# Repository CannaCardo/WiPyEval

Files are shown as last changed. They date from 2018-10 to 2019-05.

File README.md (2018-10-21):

# WiPy Eval
> WiPy 3.0 Evaluation board 




The board incorporates USB-UART bridge, micro SD card holder and temperature/ humidity sensor. The board was designed to be used by students, and as such has current limiting resistors in series with buttons in case of accidental press while GPIO is used by other peripherals. It also uses stackable headers for ease of connection and usage with both breadbords and shields/ modules.



## Release History

* 0.1.0
    * First Prototype

## Meta

Krzysztof Belewicz – belewicz@gmail.com

Distributed under the Beerware license. If you decide to build your own feel free to send me a pic.

[https://github.com/CannaCardo/github-link](https://github.com/CannaCardo/)

<!-- Markdown link & img dfn's -->
[Ver-image]: https://img.shields.io/badge/Version-1.0-orange.svg?longCache=true&style=flat-square
[Stat-image]: https://img.shields.io/badge/Status-Manufacture-green.svg?longCache=true&style=flat-square
[wiki]: https://github.com/CannaCardo/WiPy_Eval/wiki

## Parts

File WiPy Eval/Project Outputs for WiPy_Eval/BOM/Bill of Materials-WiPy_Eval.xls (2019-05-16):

Designator | Description | Value | Tolerance | MaxVoltage | Quantity | Manufacturer 1 | Manufacturer Part Number 1 | Supplier 1 | Supplier Part Number 1 | Manufacturer 2 | Manufacturer Part Number 2 | Supplier 2 | Supplier Part Number 2
A1, A2 | Bluetooth / WLAN / WiFi Ceramic Chip Antenna W x L x H (3.2 x 1.6 x 1.1 mm) |  |  |  | 2 | Pulse Electronics (https://octopart-clicks.com/click/altium?sku=2897223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) | W3008 (https://octopart-clicks.com/click/altium?sku=2897223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) | Farnell | 2897223 (https://octopart-clicks.com/click/altium?sku=2897223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) | Pulse Electronics (https://octopart-clicks.com/click/altium?sku=673-W3008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) | W3008 (https://octopart-clicks.com/click/altium?sku=673-W3008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) | Mouser | 673-W3008 (https://octopart-clicks.com/click/altium?sku=673-W3008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)
A3 | 1.575 GHz (GPS L1) 3 dBi SMD 50Ohm chip antenna, 3216 (metric) 3.2x1.6x0.6 mm |  |  |  | 1 | Walsin Technologies (https://octopart-clicks.com/click/altium?sku=RFECA3216060E0T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) | RFECA3216060E0T (https://octopart-clicks.com/click/altium?sku=RFECA3216060E0T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) | TME | RFECA3216060E0T (https://octopart-clicks.com/click/altium?sku=RFECA3216060E0T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)
C1, C2, C7, C13, C15, C20, C24 | 0402 SMD Capacitor | 2.2u | 10% | 6.3V | 7 | Murata (https://octopart-clicks.com/click/altium?sku=2672104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) | GRT155C80J225KE01D (https://octopart-clicks.com/click/altium?sku=2672104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) | Farnell | 2672104 (https://octopart-clicks.com/click/altium?sku=2672104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) | Samsung (https://octopart-clicks.com/click/altium?sku=CL05A225KQ5NSNC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) | CL05A225KQ5NSNC (https://octopart-clicks.com/click/altium?sku=CL05A225KQ5NSNC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) | TME | CL05A225KQ5NSNC (https://octopart-clicks.com/click/altium?sku=CL05A225KQ5NSNC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)
C3, C8, C11, C12, C14, C16, C17, C19, C21, C23, C37, C40, C47 | 0402 SMD Capacitor | 100n | 10% | 16V | 13 | Multicomp (https://octopart-clicks.com/click/altium?sku=2627343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) | MC0402B104K100CT (https://octopart-clicks.com/click/altium?sku=2627343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) | Farnell | 2627343 (https://octopart-clicks.com/click/altium?sku=2627343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) | Samsung (https://octopart-clicks.com/click/altium?sku=CL05B104KO5NNNC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) | CL05B104KO5NNNC (https://octopart-clicks.com/click/altium?sku=CL05B104KO5NNNC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) | TME | CL05B104KO5NNNC (https://octopart-clicks.com/click/altium?sku=CL05B104KO5NNNC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)
C4, C6, C25, C26, C27, C28, C29, C30, C46 | 0402 SMD Capacitor | DNP |  |  | 9
C5 | 0402 SMD Capacitor | 100p | 10% | 25V | 1 | Kyocera AVX (https://octopart-clicks.com/click/altium?sku=04025A101JAT2A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) | 04025A101JAT2A (https://octopart-clicks.com/click/altium?sku=04025A101JAT2A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) | TME | 04025A101JAT2A (https://octopart-clicks.com/click/altium?sku=04025A101JAT2A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) | Multicomp (https://octopart-clicks.com/click/altium?sku=1758898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) | MC0402B101K250CT (https://octopart-clicks.com/click/altium?sku=1758898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) | Farnell | 1758898 (https://octopart-clicks.com/click/altium?sku=1758898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)
C9, C10, C31, C33, C35, C38, C41, C43 | 0402 SMD Capacitor | 10p | 5% | 50V | 8 | Vishay (https://octopart-clicks.com/click/altium?sku=2896329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) | VJ0402A100JXACW1BC (https://octopart-clicks.com/click/altium?sku=2896329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) | Farnell | 2896329 (https://octopart-clicks.com/click/altium?sku=2896329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) | Vishay Vitramon (https://octopart-clicks.com/click/altium?sku=VJ0402A100FXACW1BC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) | VJ0402A100FXACW1BC (https://octopart-clicks.com/click/altium?sku=VJ0402A100FXACW1BC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) | TME | VJ0402A100FXACW1BC (https://octopart-clicks.com/click/altium?sku=VJ0402A100FXACW1BC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)
C22 | Polarized Capacitor (Surface Mount) | 330uF | 10% |  | 1 | Kyocera AVX (https://octopart-clicks.com/click/altium?sku=TAJD337K006R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) | TAJD337K006RNJ (https://octopart-clicks.com/click/altium?sku=TAJD337K006R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) | TME | TAJD337K006R (https://octopart-clicks.com/click/altium?sku=TAJD337K006R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)
C32, C34, C36, C39, C42, C44 | 0402 SMD Capacitor | 33p | 5% | 50V | 6 | Walsin Technologies (https://octopart-clicks.com/click/altium?sku=2496802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) | 0402N330J500CT (https://octopart-clicks.com/click/altium?sku=2496802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) | Farnell | 2496802 (https://octopart-clicks.com/click/altium?sku=2496802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) | Murata (https://octopart-clicks.com/click/altium?sku=GRM1555C1H330JA01D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) | GRM1555C1H330JA01D (https://octopart-clicks.com/click/altium?sku=GRM1555C1H330JA01D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) | TME | GRM1555C1H330JA01D (https://octopart-clicks.com/click/altium?sku=GRM1555C1H330JA01D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)
C48, C49, C50, C51, C52, C53 | 0603 imperial SMD Capacitor | 1u | 10% | 16V | 6 | Samsung (https://octopart-clicks.com/click/altium?sku=CL10B105KO8NNNC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) | CL10B105KO8NNNC (https://octopart-clicks.com/click/altium?sku=CL10B105KO8NNNC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) | TME | CL10B105KO8NNNC (https://octopart-clicks.com/click/altium?sku=CL10B105KO8NNNC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)
C54 | 0402 SMD Capacitor | 47u | 20% | 6.3V | 1 | Samsung (https://octopart-clicks.com/click/altium?sku=CL05B104KO5NNNC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) | CL05B104KO5NNNC (https://octopart-clicks.com/click/altium?sku=CL05B104KO5NNNC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) | TME | CL05B104KO5NNNC (https://octopart-clicks.com/click/altium?sku=CL05B104KO5NNNC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)
D1, D2 | LED; SMD; 3528,PLCC4; RGB; 3,5x2,8x1,9mm; 115°; 20mA; Common anode |  |  |  | 2 | Broadcom Avago (https://octopart-clicks.com/click/altium?sku=2401106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) | ASMB-MTB1-0A3A2 (https://octopart-clicks.com/click/altium?sku=2401106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) | Farnell | 2401106 (https://octopart-clicks.com/click/altium?sku=2401106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) | Broadcom (https://octopart-clicks.com/click/altium?sku=ASMB-MTB1-0A3A2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) | ASMB-MTB1-0A3A2 (https://octopart-clicks.com/click/altium?sku=ASMB-MTB1-0A3A2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) | TME | ASMB-MTB1-0A3A2 (https://octopart-clicks.com/click/altium?sku=ASMB-MTB1-0A3A2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)
D3 | Schottky Diodes; Repetitive Reverse Voltage Max, Vrrm: 40V; Forward Current, If_AV_: 1A; Forward Voltage Max, VF: 0.5... |  |  |  | 1 | Microsemi (https://octopart-clicks.com/click/altium?sku=1467537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) | SS14 (https://octopart-clicks.com/click/altium?sku=1467537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) | Farnell | 1467537 (https://octopart-clicks.com/click/altium?sku=1467537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) | ON Semiconductor / Fairchild (https://octopart-clicks.com/click/altium?sku=512-SS14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) | SS14 (https://octopart-clicks.com/click/altium?sku=512-SS14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) | Mouser | 512-SS14 (https://octopart-clicks.com/click/altium?sku=512-SS14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)
F1, F2 | PTC Fuse 750mA |  |  |  | 2 | Excel Cell (https://octopart-clicks.com/click/altium?sku=SR075-06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) | SR075-06 (https://octopart-clicks.com/click/altium?sku=SR075-06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) | TME | SR075-06 (https://octopart-clicks.com/click/altium?sku=SR075-06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)
F3 | PTC Fuse 3A |  |  |  | 1 | Bel (https://octopart-clicks.com/click/altium?sku=2834915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) | 0ZCG0300FF2B (https://octopart-clicks.com/click/altium?sku=2834915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) | Farnell | 2834915 (https://octopart-clicks.com/click/altium?sku=2834915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) | Bel (https://octopart-clicks.com/click/altium?sku=530-0ZCF0300AF2C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) | 0ZCF0300AF2C (https://octopart-clicks.com/click/altium?sku=530-0ZCF0300AF2C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) | Mouser | 530-0ZCF0300AF2C (https://octopart-clicks.com/click/altium?sku=530-0ZCF0300AF2C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)
FB1, FB2, FB3, FB4 | Ferrite Bead | 120@100MHz | 25% |  | 4 | Murata (https://octopart-clicks.com/click/altium?sku=2443229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) | BLM15PD121SN1D (https://octopart-clicks.com/click/altium?sku=2443229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) | Farnell | 2443229 (https://octopart-clicks.com/click/altium?sku=2443229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) | Murata (https://octopart-clicks.com/click/altium?sku=BLM15PD121SN1D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) | BLM15PD121SN1D (https://octopart-clicks.com/click/altium?sku=BLM15PD121SN1D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) | TME | BLM15PD121SN1D (https://octopart-clicks.com/click/altium?sku=BLM15PD121SN1D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)
J1, J2, J3, J4, J5, J6, J8, J9, J10, J11, J12, J13 | 1x2, 2.54mm Black header jumper |  |  |  | 12 | Multicomp (https://octopart-clicks.com/click/altium?sku=2834673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) | MC-2228CG (https://octopart-clicks.com/click/altium?sku=2834673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) | Farnell | 2834673 (https://octopart-clicks.com/click/altium?sku=2834673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) | Ninigi (https://octopart-clicks.com/click/altium?sku=JUMPER-B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) | JUMPER-B (https://octopart-clicks.com/click/altium?sku=JUMPER-B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) | TME | JUMPER-B (https://octopart-clicks.com/click/altium?sku=JUMPER-B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)
J7 | SMA Female, 90 Angle, THT, Golded, Teflon Isolated |  |  |  | 1 |  |  | TME | SMA-15
J16 | Molex 78800 Series Vertical Hinged Micro SIM Card Connector with SMT Termination |  |  |  | 1 | Molex (https://octopart-clicks.com/click/altium?sku=538-78800-0001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) | 78800-0001 (https://octopart-clicks.com/click/altium?sku=538-78800-0001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) | Mouser | 538-78800-0001 (https://octopart-clicks.com/click/altium?sku=538-78800-0001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) | Molex (https://octopart-clicks.com/click/altium?sku=MX-78800-0001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) | 78800-0001 (https://octopart-clicks.com/click/altium?sku=MX-78800-0001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) | TME | MX-78800-0001 (https://octopart-clicks.com/click/altium?sku=MX-78800-0001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)
P1, P7, P8, P10, P11, P12, P13, P16, P17 | Pin header, 1x3, 2.54mm |  |  |  | 9 | Ningbo Connfly Electric (https://octopart-clicks.com/click/altium?sku=ZL201-03G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) | DS1021-1*3SF1-1 (https://octopart-clicks.com/click/altium?sku=ZL201-03G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) | TME | ZL201-03G (https://octopart-clicks.com/click/altium?sku=ZL201-03G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)
P2 | Hirose UFL connector |  |  |  | 1 | Hirose (https://octopart-clicks.com/click/altium?sku=1688077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) | U.FL-R-SMT-1(10) (https://octopart-clicks.com/click/altium?sku=1688077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) | Farnell | 1688077 (https://octopart-clicks.com/click/altium?sku=1688077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) | Hirose (https://octopart-clicks.com/click/altium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) | U.FL-R-SMT-1(10) (https://octopart-clicks.com/click/altium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) | TME | U.FL-R-SMT-1-10/C (https://octopart-clicks.com/click/altium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)
P3, P5 | Header, 16-Pin |  |  |  | 2 | Harwin (https://octopart-clicks.com/click/altium?sku=855-M20-7821646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) | M20-7821646 (https://octopart-clicks.com/click/altium?sku=855-M20-7821646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) | Mouser | 855-M20-7821646 (https://octopart-clicks.com/click/altium?sku=855-M20-7821646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) | Harwin (https://octopart-clicks.com/click/altium?sku=855-M20-7821646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) | M20-7821646 (https://octopart-clicks.com/click/altium?sku=855-M20-7821646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) | Mouser | 855-M20-7821646 (https://octopart-clicks.com/click/altium?sku=855-M20-7821646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)
P4 | Memory Card Connectors Micro SD 8 Pin PCB Gold |  |  |  | 1 | Amphenol Commercial (https://octopart-clicks.com/click/altium?sku=2666772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) | 114-00841-68 (https://octopart-clicks.com/click/altium?sku=2666772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) | Farnell | 2666772 (https://octopart-clicks.com/click/altium?sku=2666772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) | Amphenol ICC (https://octopart-clicks.com/click/altium?sku=523-114-00841-68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) | 1140084168 (https://octopart-clicks.com/click/altium?sku=523-114-00841-68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) | Mouser | 523-114-00841-68 (https://octopart-clicks.com/click/altium?sku=523-114-00841-68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)
P6, P14 | Gniazdo; USB B mini; SMT; poziome; V: USB 2.0; złocony |  |  |  | 2 | Adam Tech (https://octopart-clicks.com/click/altium?sku=MUSB-B5-S-RA-SMT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) | MUSB-B5-S-RA-TSMT-CS1 (https://octopart-clicks.com/click/altium?sku=MUSB-B5-S-RA-SMT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) | TME | MUSB-B5-S-RA-SMT (https://octopart-clicks.com/click/altium?sku=MUSB-B5-S-RA-SMT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)
P9 | Socket; Barrel jack DC; male; 5,5/2,1mm; SMD |  |  |  | 1 | Cliff (https://octopart-clicks.com/click/altium?sku=FC68148S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) | DC-10AS(FC68148S) (https://octopart-clicks.com/click/altium?sku=FC68148S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) | TME | FC68148S (https://octopart-clicks.com/click/altium?sku=FC68148S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)
P15, P18 | Jack Socket, 1/4" [6.5mm], Thru-Hole, Vertical, 2-Conductor Open Circuit |  |  |  | 2 | Lumberg (https://octopart-clicks.com/click/altium?sku=1503-13VP3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) | 150313VP3 (https://octopart-clicks.com/click/altium?sku=1503-13VP3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) | TME | 1503-13VP3 (https://octopart-clicks.com/click/altium?sku=1503-13VP3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)
Q1, Q2, Q3 | Tranzystor: NPN; bipolarny; 45V; 200mA; 200mW; SOT323 |  |  |  | 3 | Nexperia (https://octopart-clicks.com/click/altium?sku=BC847AW.115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) | BC847AW.115 (https://octopart-clicks.com/click/altium?sku=BC847AW.115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) | TME | BC847AW.115 (https://octopart-clicks.com/click/altium?sku=BC847AW.115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)
R1, R5, R7, R12, R16, R17, R20, R24, R28, R29, R30, R31, R33, R34, R35, R36, R38, R39, R40 | 0402 Film SMD Resistor | 1k | 1% |  | 19 | TE Connectivity Neohm (https://octopart-clicks.com/click/altium?sku=1174154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) | CRG0402J1K0 (https://octopart-clicks.com/click/altium?sku=1174154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) | Farnell | 1174154 (https://octopart-clicks.com/click/altium?sku=1174154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) | Vishay (https://octopart-clicks.com/click/altium?sku=CRCW04021K00FKTDBC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) | CRCW04021K00FKTDBC (https://octopart-clicks.com/click/altium?sku=CRCW04021K00FKTDBC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) | TME | CRCW04021K00FKTDBC (https://octopart-clicks.com/click/altium?sku=CRCW04021K00FKTDBC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)
R2, R3, R4, R6, R18, R19, R21 | 0402 Film SMD Resistor | 150 | 1% |  | 7 | TE Connectivity (https://octopart-clicks.com/click/altium?sku=2861390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) | CRGCQ0402F150R (https://octopart-clicks.com/click/altium?sku=2861390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) | Farnell | 2861390 (https://octopart-clicks.com/click/altium?sku=2861390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) | Yageo (https://octopart-clicks.com/click/altium?sku=RC0402FR-07150R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) | RC0402FR-07150R (https://octopart-clicks.com/click/altium?sku=RC0402FR-07150R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) | TME | RC0402FR-07150R (https://octopart-clicks.com/click/altium?sku=RC0402FR-07150R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)
R8, R27, R32, R37 | 0402 Film SMD Resistor | 0 | 1% |  | 4 | Panasonic (https://octopart-clicks.com/click/altium?sku=ERJ2GE0R00X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) | ERJ-2GE0R00X (https://octopart-clicks.com/click/altium?sku=ERJ2GE0R00X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) | Farnell | ERJ2GE0R00X (https://octopart-clicks.com/click/altium?sku=ERJ2GE0R00X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)
R9, R42 | 0402 Film SMD Resistor | 100k | 1% |  | 2 | ROYAL OHM (https://octopart-clicks.com/click/altium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) | CQ02WGF1003TCE (https://octopart-clicks.com/click/altium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) | TME | CQ0402-100K-1% (https://octopart-clicks.com/click/altium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)
R10 | 0402 Film SMD Resistor | 470 | 5% |  | 1 | Royal Electronic Factory (https://octopart-clicks.com/click/altium?manufacturer=Royal%20Electronic%20Factory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) | 0402WGJ0471TCE (https://octopart-clicks.com/click/altium?manufacturer=Royal%20Electronic%20Factory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) | TME | SMD0402-470R (https://octopart-clicks.com/click/altium?manufacturer=Royal%20Electronic%20Factory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)
R11, R13, R14, R22, R25, R26 | 0402 Film SMD Resistor | 22k | 1% |  | 6 | TE Connectivity (https://octopart-clicks.com/click/altium?sku=2861416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) | CRGCQ0402F22K (https://octopart-clicks.com/click/altium?sku=2861416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) | Farnell | 2861416 (https://octopart-clicks.com/click/altium?sku=2861416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) | Vishay (https://octopart-clicks.com/click/altium?sku=CRCW040222K0FKTDBC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) | CRCW040222K0FKTDBC (https://octopart-clicks.com/click/altium?sku=CRCW040222K0FKTDBC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) | TME | CRCW040222K0FKTDBC (https://octopart-clicks.com/click/altium?sku=CRCW040222K0FKTDBC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)
R15 | 0402 Film SMD Resistor | 47k | 1% |  | 1 | Multicomp (https://octopart-clicks.com/click/altium?sku=2447179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) | MCWR04X4702FTL (https://octopart-clicks.com/click/altium?sku=2447179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) | Farnell | 2447179 (https://octopart-clicks.com/click/altium?sku=2447179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) | Royal Electronic Factory (https://octopart-clicks.com/click/altium?manufacturer=Royal%20Electronic%20Factory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) | 0402WGF4702TCE (https://octopart-clicks.com/click/altium?manufacturer=Royal%20Electronic%20Factory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) | TME | SMD0402-47K-1% (https://octopart-clicks.com/click/altium?manufacturer=Royal%20Electronic%20Factory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)
R23 | 0402 Film SMD Resistor | 43k | 1% |  | 1 | Multicomp (https://octopart-clicks.com/click/altium?sku=2073032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) | MCMR04X4302FTL (https://octopart-clicks.com/click/altium?sku=2073032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) | Farnell | 2073032 (https://octopart-clicks.com/click/altium?sku=2073032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) | ROYAL OHM (https://octopart-clicks.com/click/altium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) | 0402WGF4302TCE (https://octopart-clicks.com/click/altium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) | TME | SMD0402-43K-1% (https://octopart-clicks.com/click/altium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)
R41, R43 | 0402 Film SMD Resistor | 390k | 1% |  | 2 | Royal Electronic Factory (https://octopart-clicks.com/click/altium?manufacturer=Royal%20Electronic%20Factory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) | 0402WGF3903TCE (https://octopart-clicks.com/click/altium?manufacturer=Royal%20Electronic%20Factory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) | TME | SMD0402-390K-1% (https://octopart-clicks.com/click/altium?manufacturer=Royal%20Electronic%20Factory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)
S1, S2, S3 | TACT; SPST-NO; 2 position; 0,05A/12VDC; SMT |  |  |  | 3 | Schurter (https://octopart-clicks.com/click/altium?sku=1217771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) | 1301.9319 (https://octopart-clicks.com/click/altium?sku=1217771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) | Farnell | 1217771 (https://octopart-clicks.com/click/altium?sku=1217771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) | Schurter (https://octopart-clicks.com/click/altium?sku=1301.9319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) | 1301.9319 (https://octopart-clicks.com/click/altium?sku=1301.9319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) | TME | 1301.9319 (https://octopart-clicks.com/click/altium?sku=1301.9319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)
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

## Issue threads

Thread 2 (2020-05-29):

CP2102N Reset

CannaCardo, 2020-05-29:
The CP2102N reset is tied to the W01 reset and the on board button - when pressed it corrupts an open UART port connection.

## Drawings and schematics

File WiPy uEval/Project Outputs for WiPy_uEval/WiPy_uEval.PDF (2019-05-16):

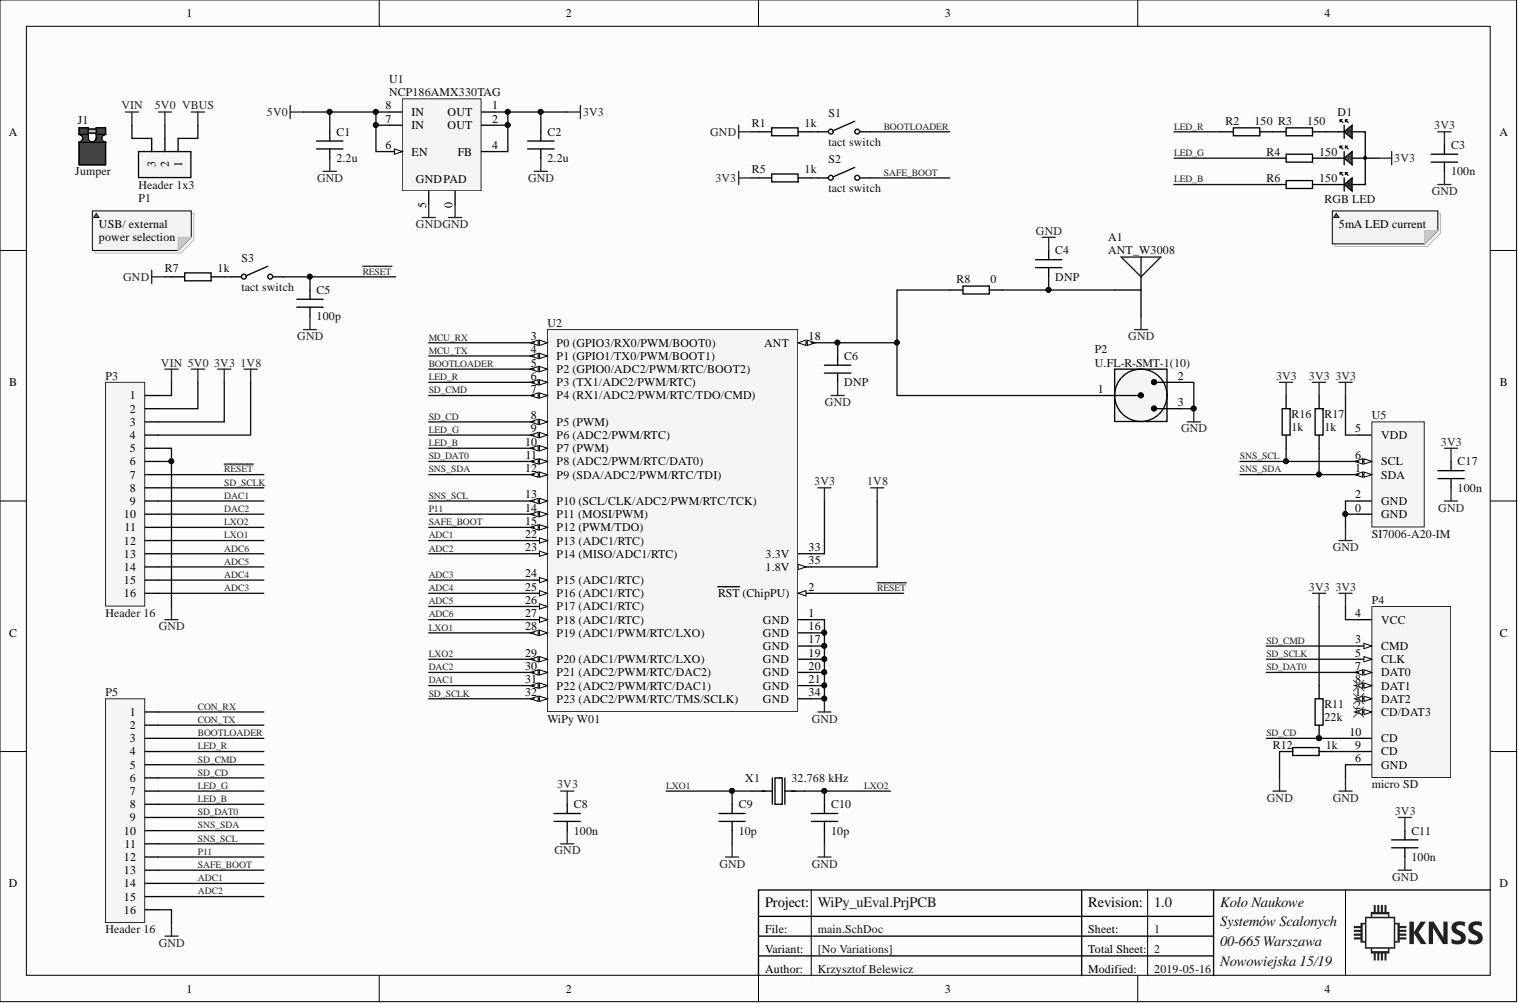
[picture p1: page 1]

1 7
1 9
2 0
2 1

Proje ct: | WiP y _uEv al.PrjPCB | Re visio n : | 1.0 | Ko ło Na u kowe Syste m ów S c alo ny c h 0 0-6 65 Warszawa Nowowiejska 1 5/1 9

Fi le: | mai n.Sch D o c | Sheet : | 12
Varian t : | [N o Variat i o n s ] | To tal Sheet :
A u t h or: | Krzy szt of Belew icz | Mo d ified : | 2 0 1 9-0 5-1 6

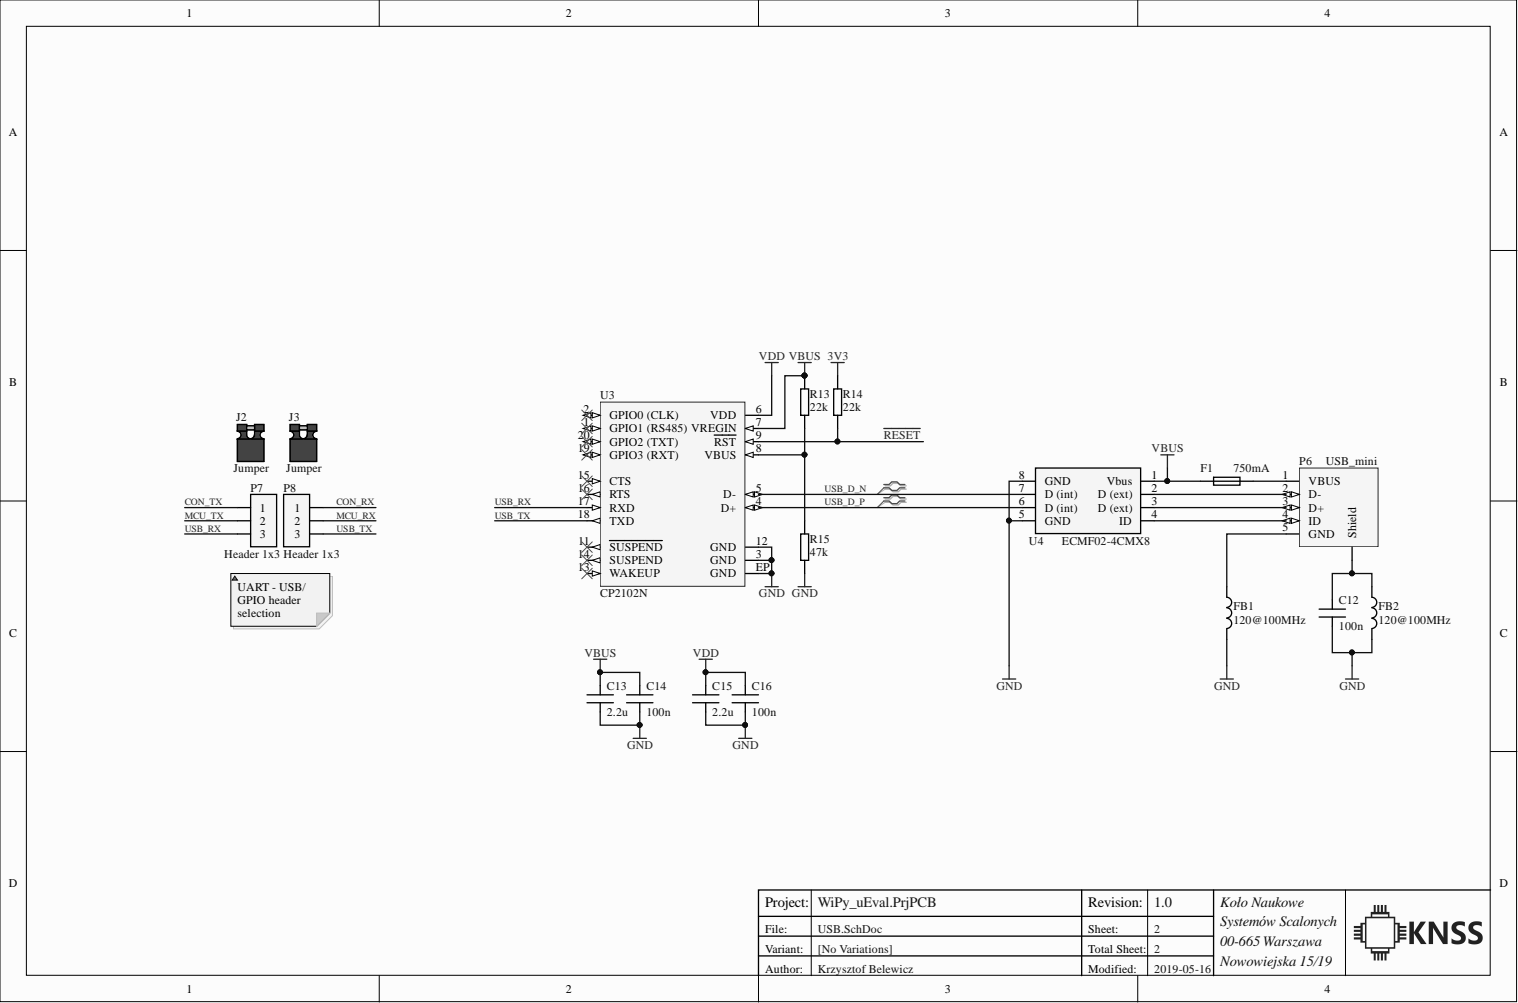
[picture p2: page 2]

E P

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

Fi le: | USB.Sch D o c | Sheet : | 22
Varian t : | [N o Variat i o n s ] | To tal Sheet :
A u t h or: | Krzy szt of Belew icz | Mo d ified : | 2 0 1 9-0 5-1 6

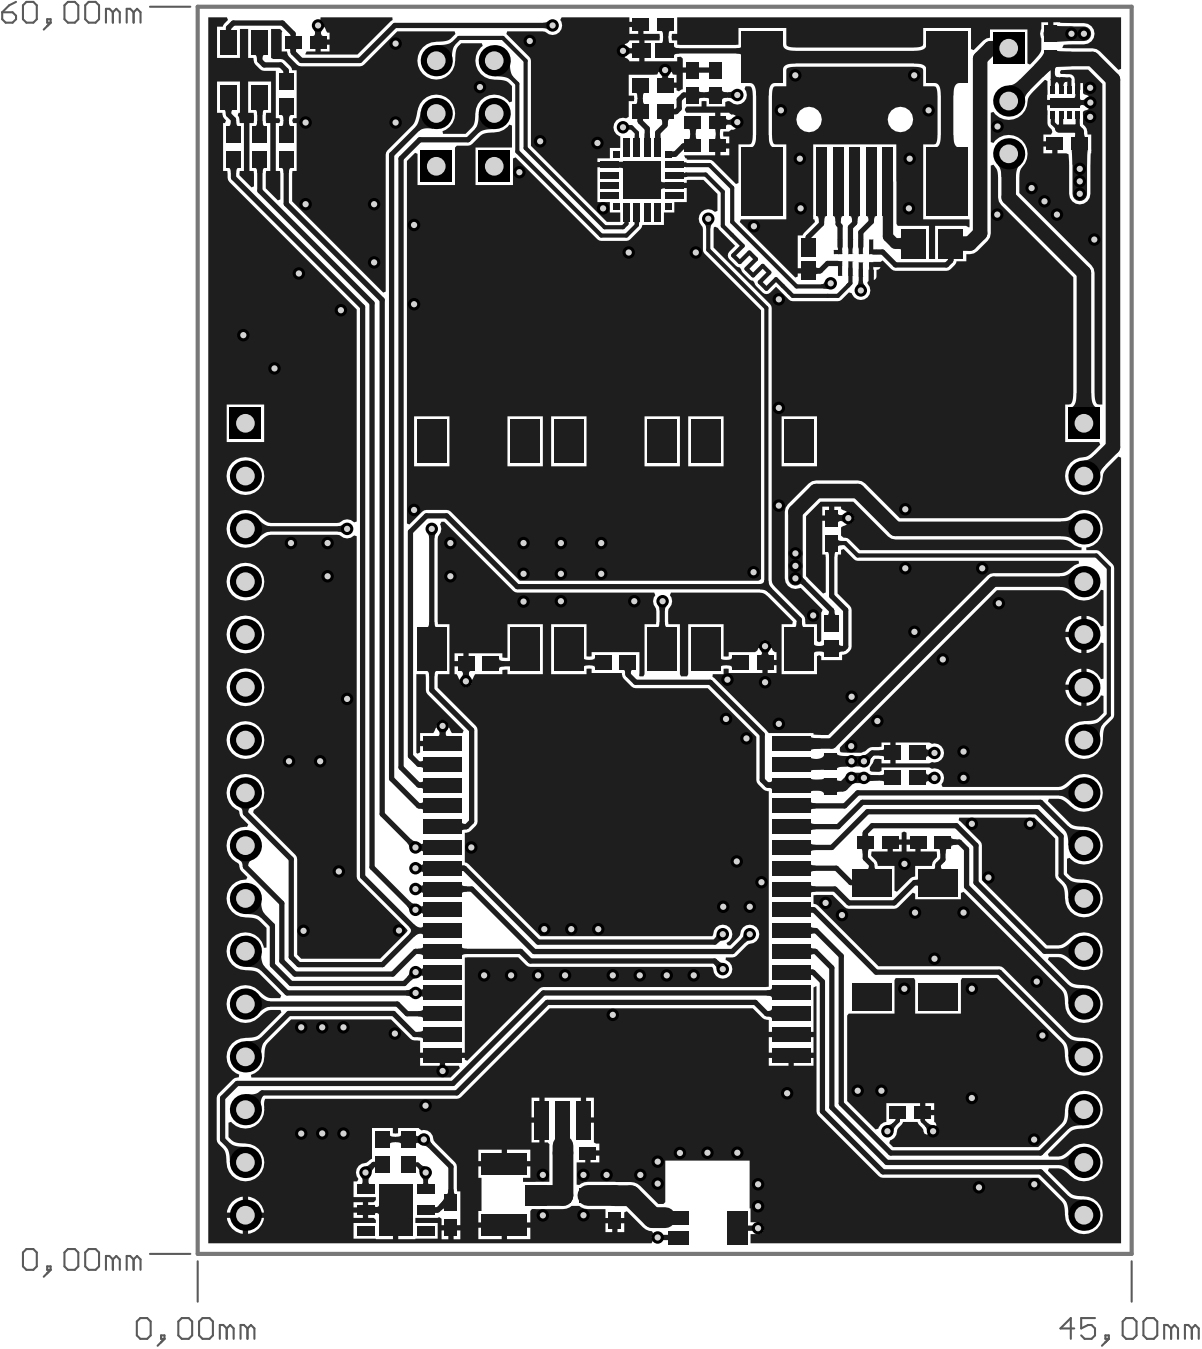
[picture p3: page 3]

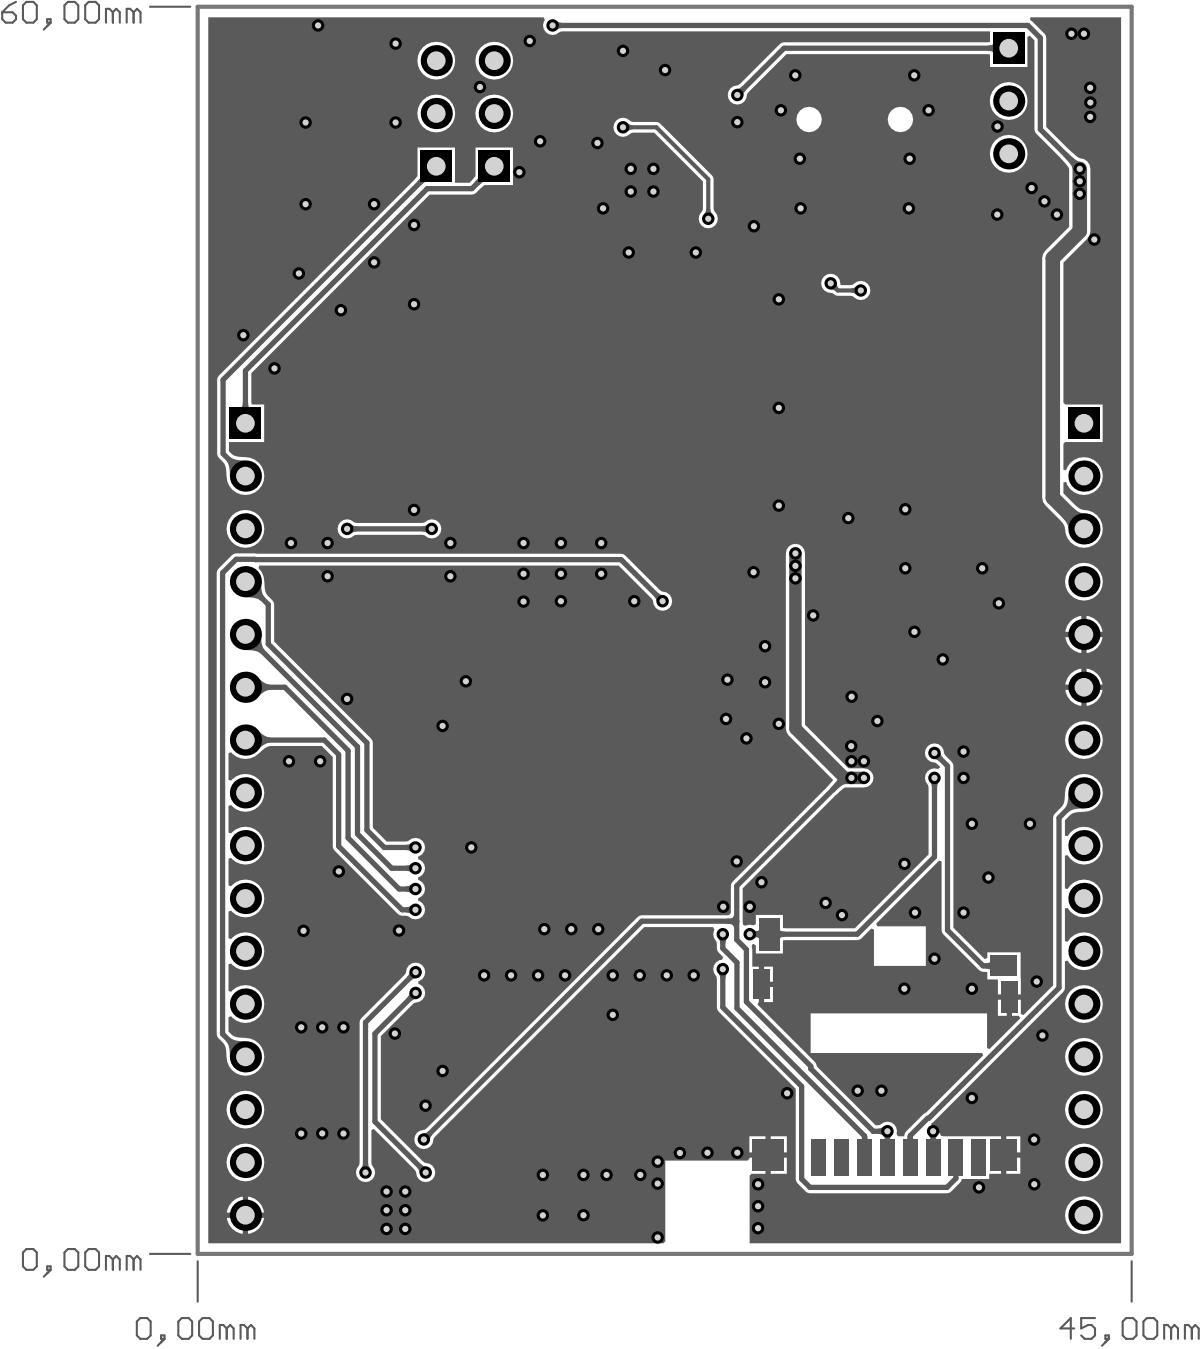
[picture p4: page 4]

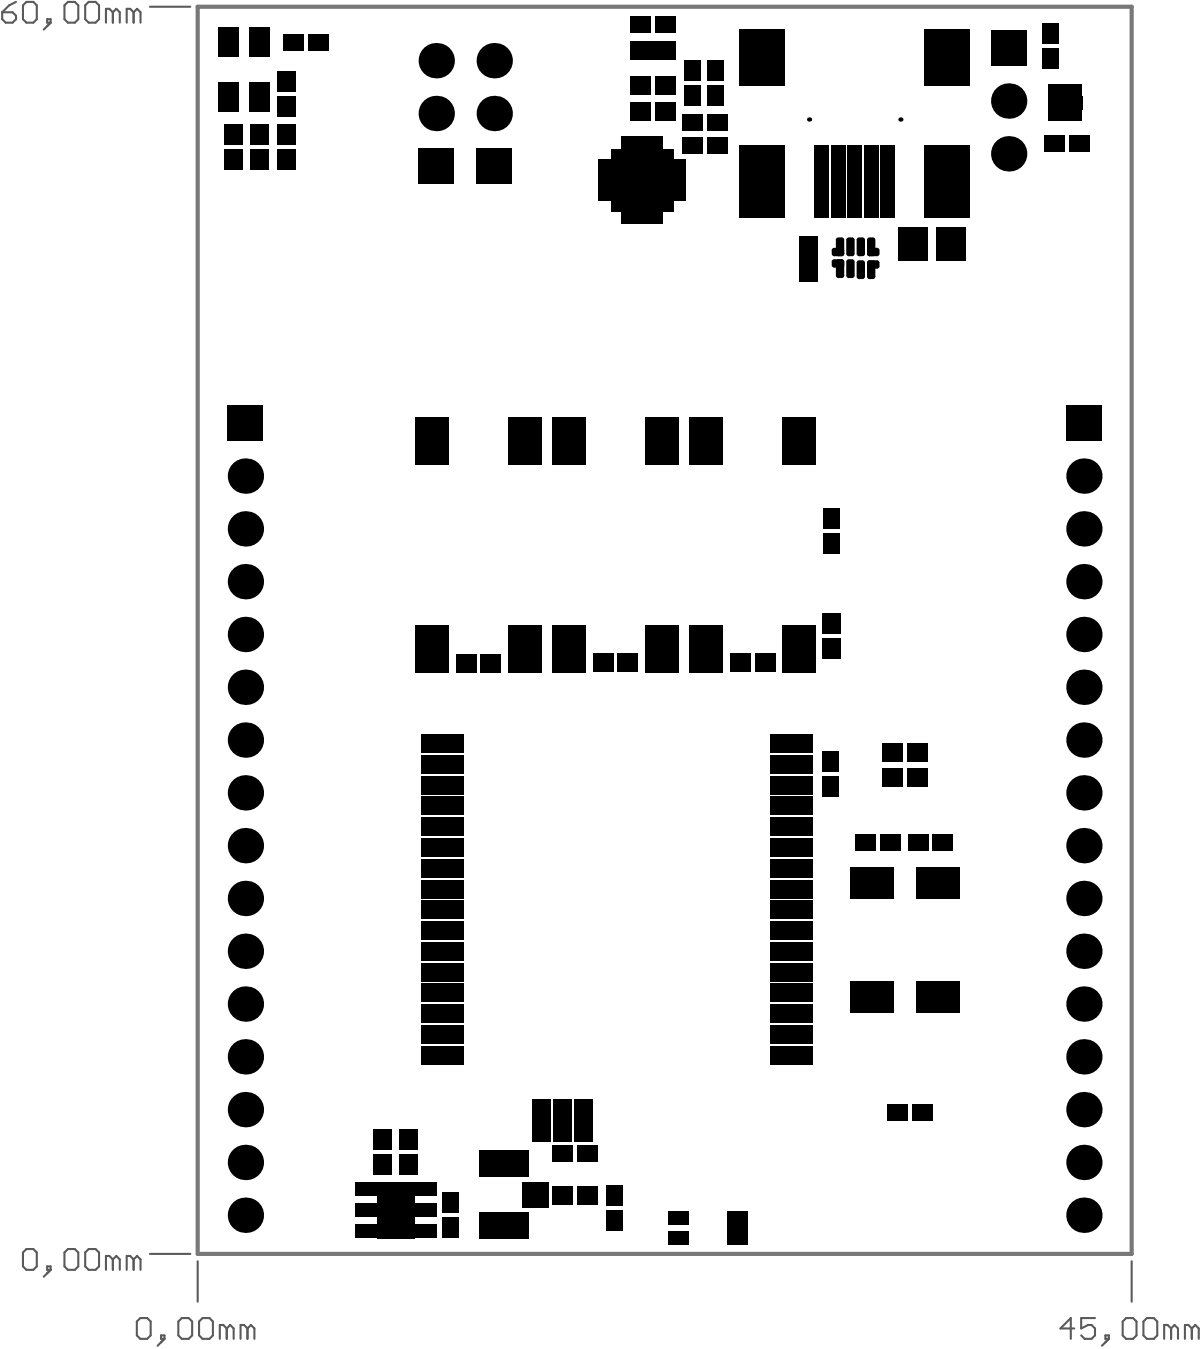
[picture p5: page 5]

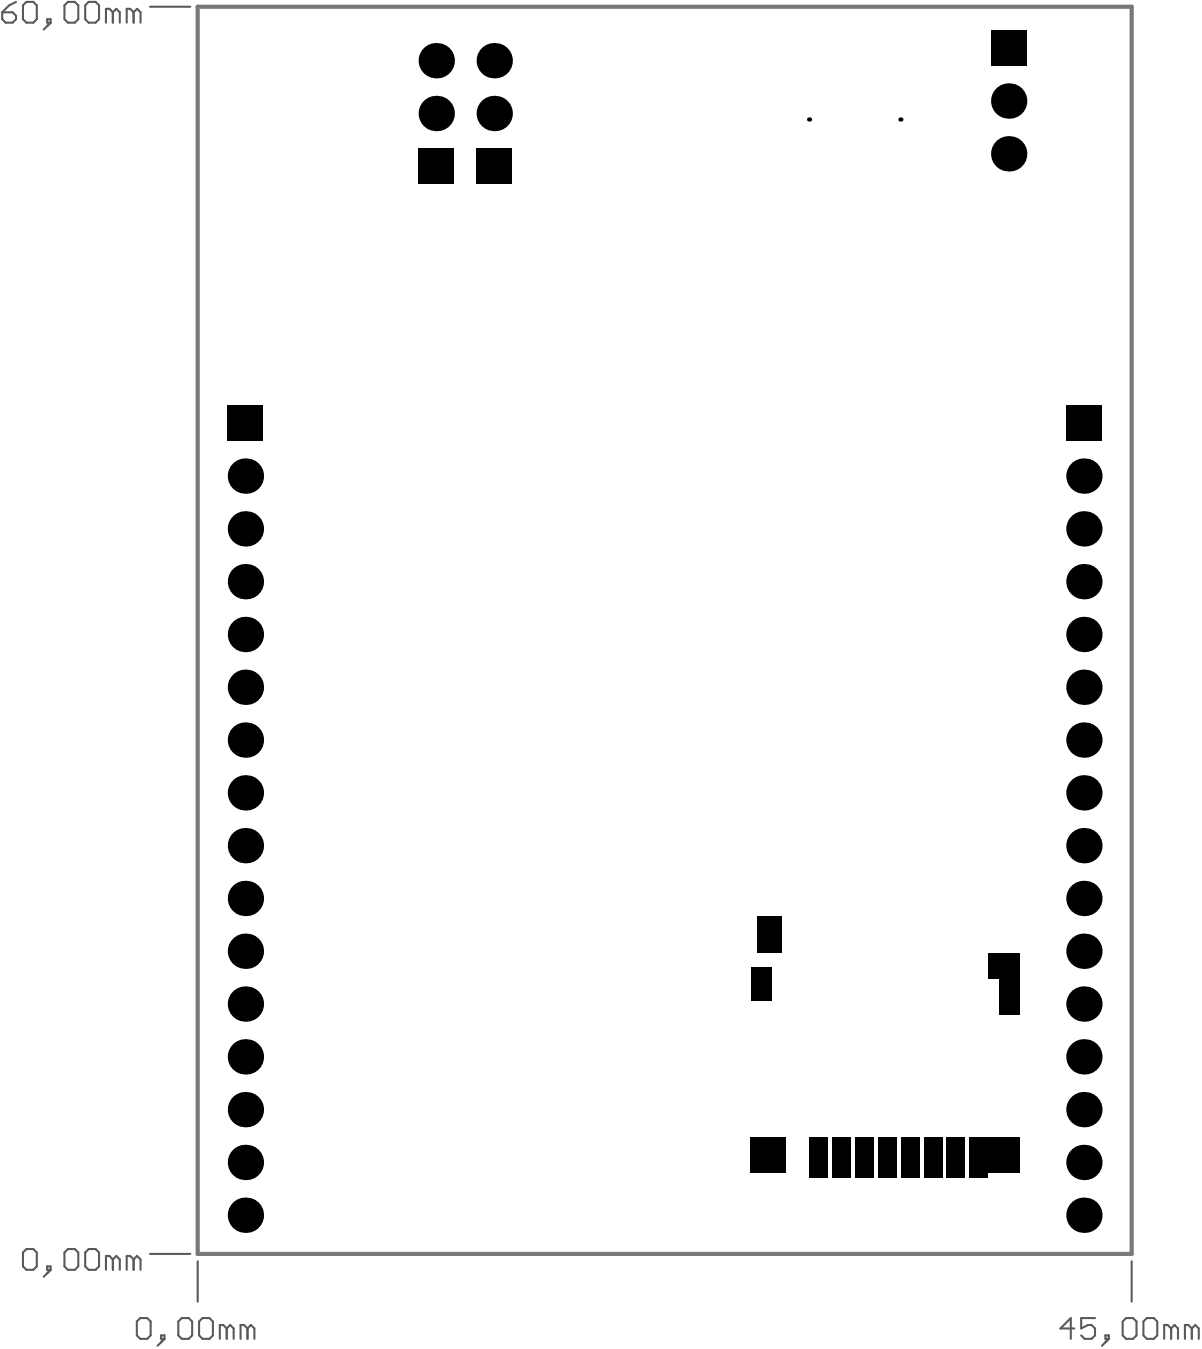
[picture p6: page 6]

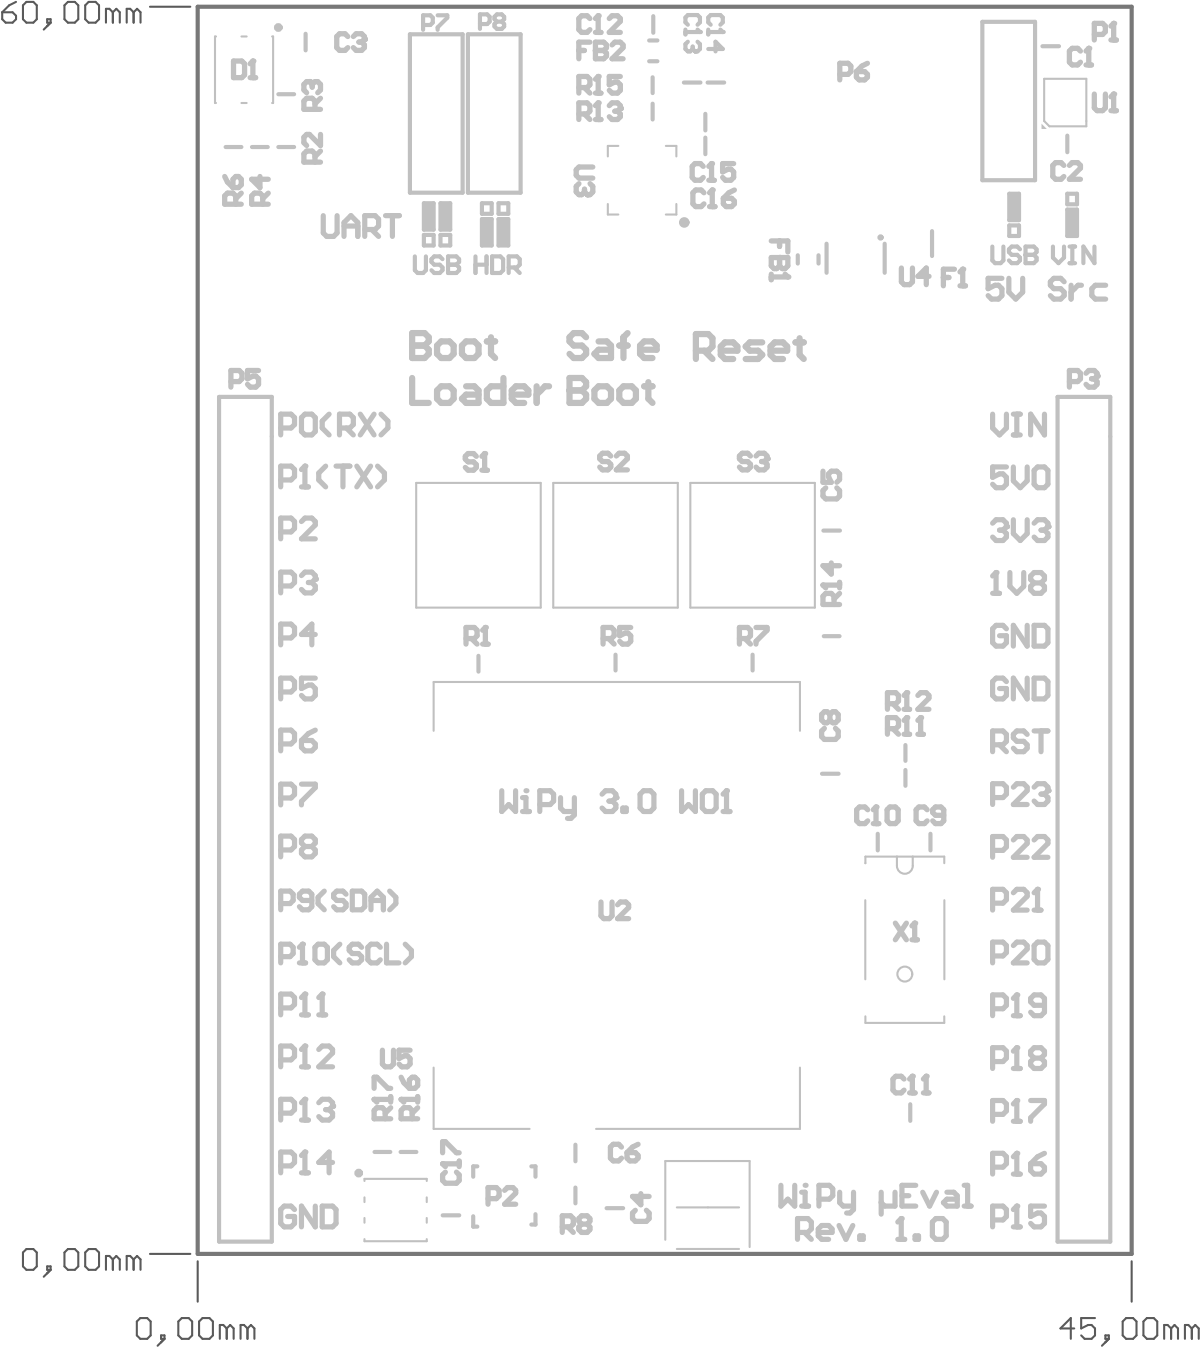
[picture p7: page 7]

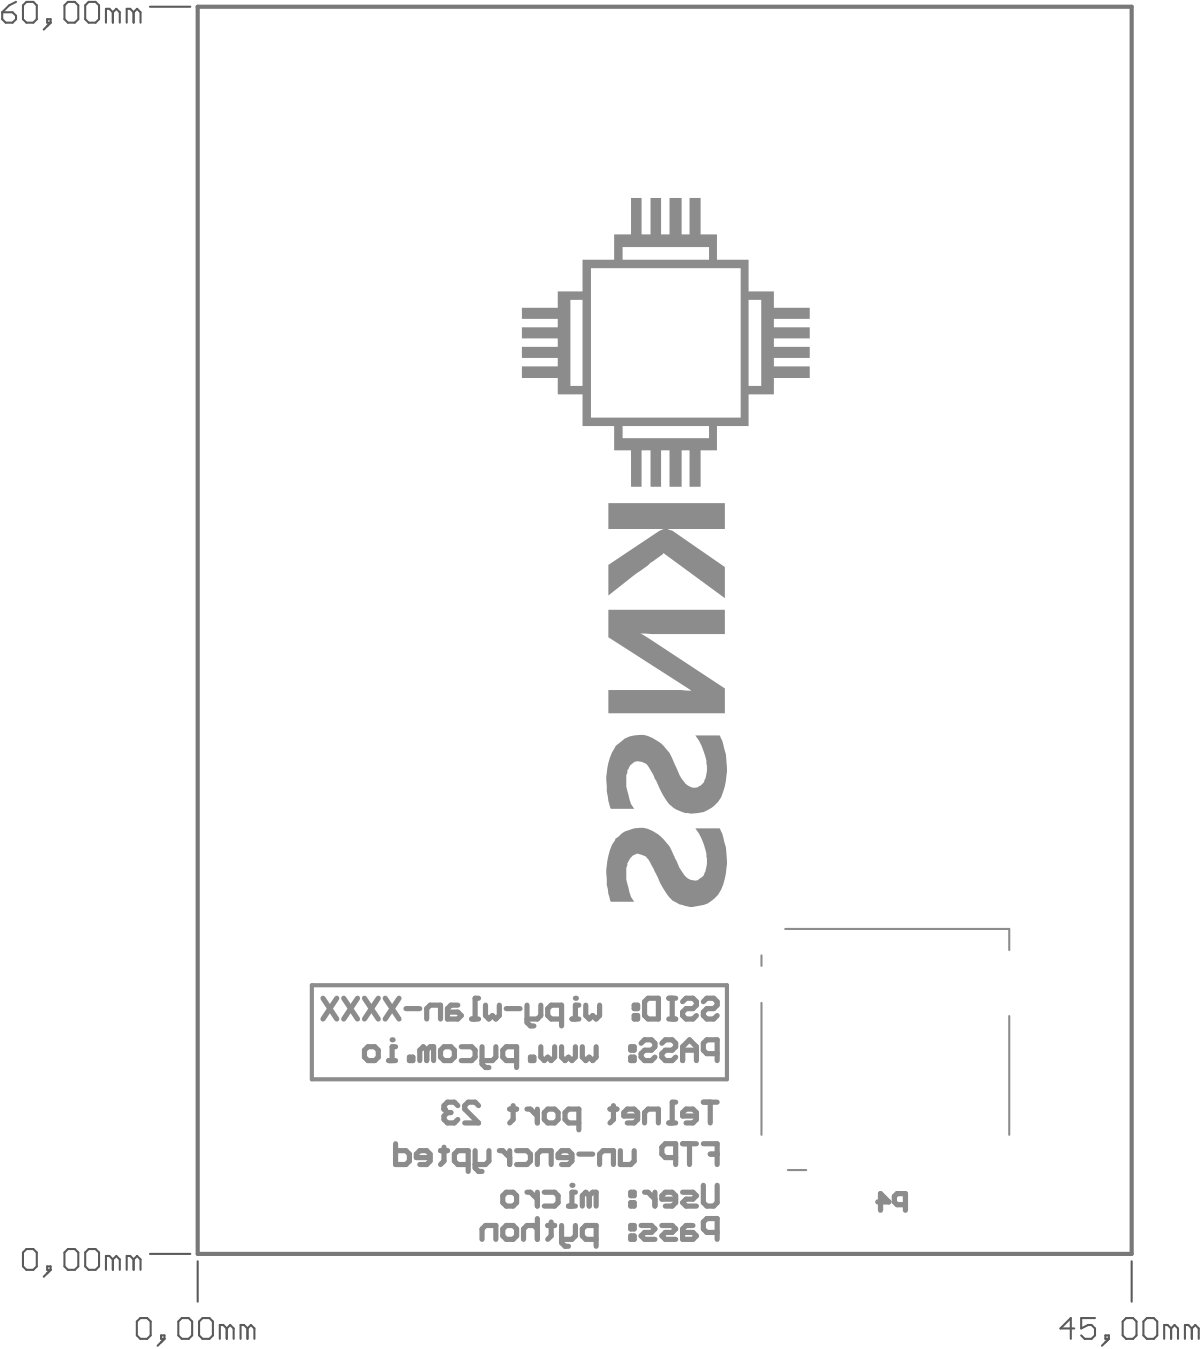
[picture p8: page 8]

# Board Stack Report

Stack Up | Layer Stack
Layer | Board Layer Stack | Name | Material | Thickness | Constant

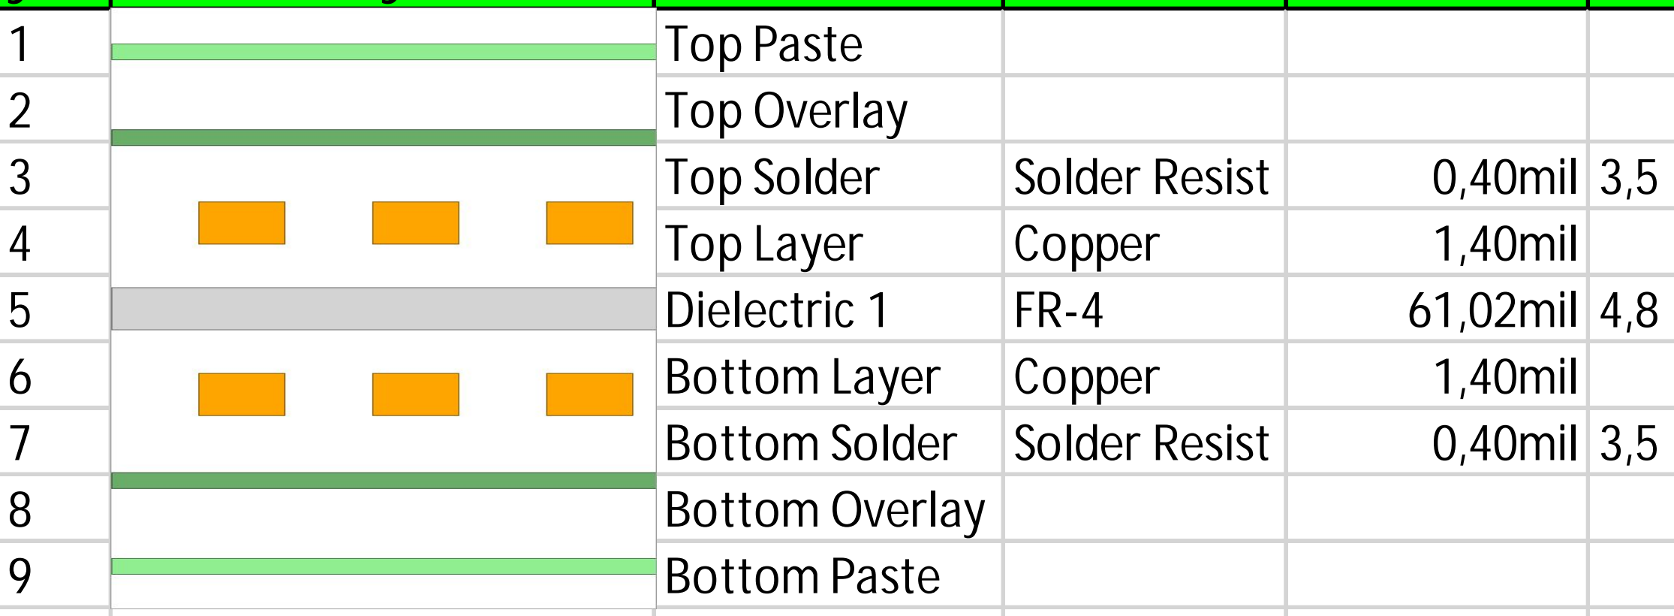
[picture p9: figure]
Top Paste; Top Overlay; Top Solder; Solder Resist; 0,40mil; Top Layer; Copper; 1,40mil; Dielectric 1; 61,02mil; Bottom Layer; Bottom Overlay; Bottom Paste

7 | | Bottom Solder | Solder Resist | 0,40mil | 3,5
| Height : 64,62mil

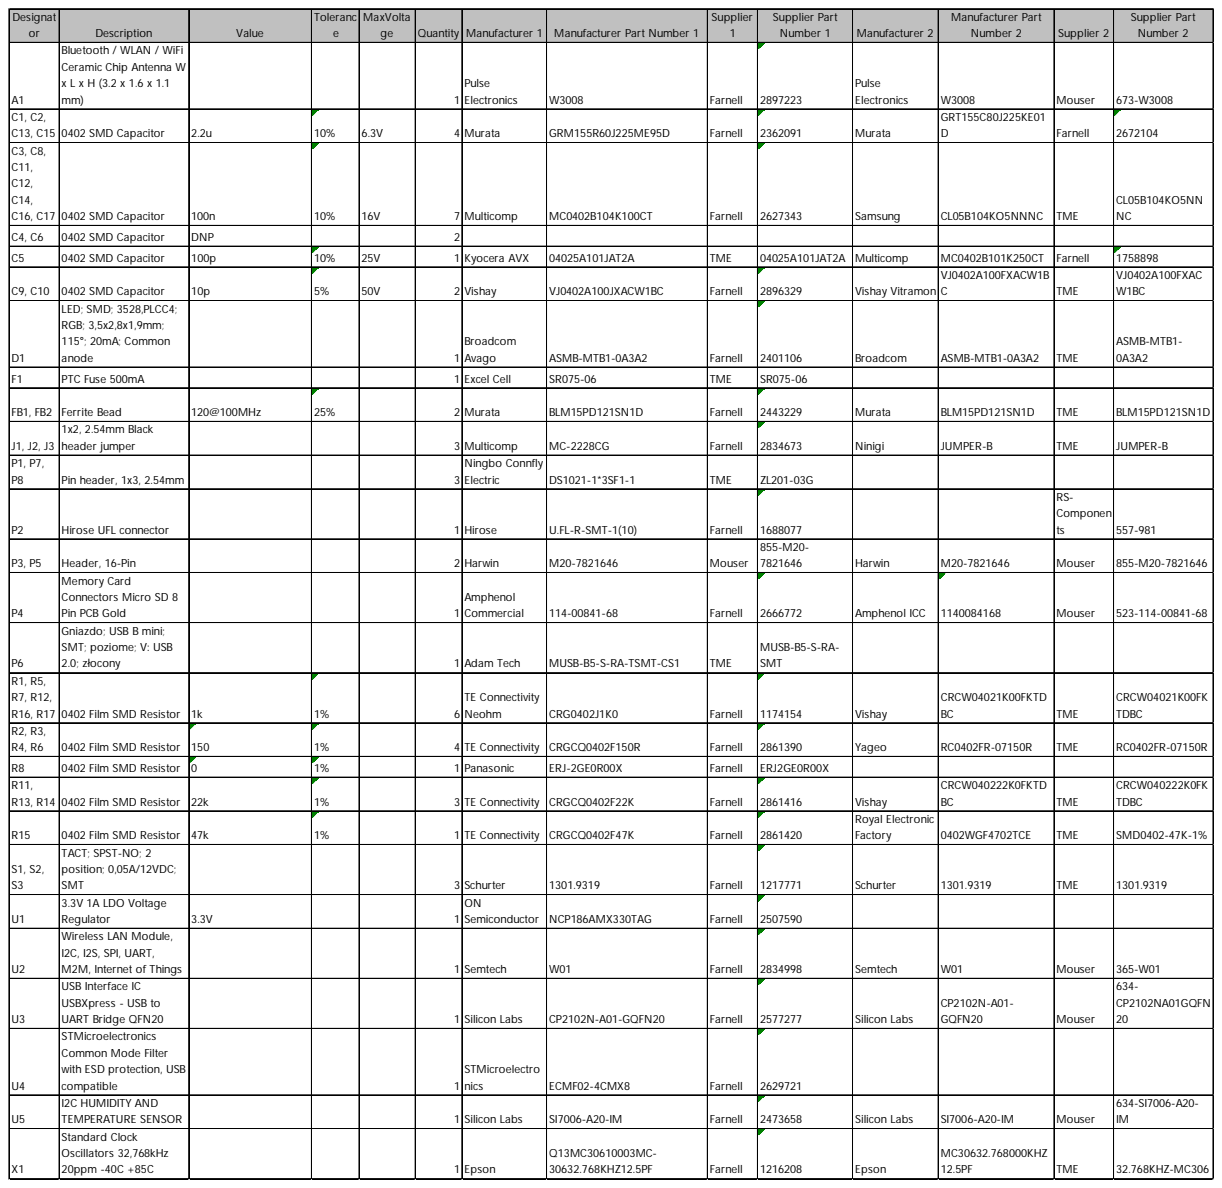
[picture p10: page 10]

Designat or | Description | Value | Toleranc e | MaxVolta ge | Quantity | Manufacturer 1 | Manufacturer Part Number 1 | Supplier 1 | Supplier Part Number 1 | Manufacturer 2 | Manufacturer Part Number 2 | Supplier 2 | Supplier Part Number 2

A1 | Bluetooth / WLAN / WiFi Ceramic Chip Antenna W x L x H (3.2 x 1.6 x 1.1 mm) | | | | 1 | Pulse Electronics | W3008 | Farnell | 2897223 | Pulse Electronics | W3008 | Mouser | 673-W3008

C1, C2, C13, C15 | 0402 SMD Capacitor | 2.2u | 10% | 6.3V | 4 | Murata | GRM155R60J225ME95D | Farnell | 2362091 | Murata | GRT155C80J225KE01 D | Farnell | 2672104

C3, C8, C11, C12, C14, C16, C17 | 0402 SMD Capacitor | 100n | 10% | 16V | 7 | Multicomp | MC0402B104K100CT | Farnell | 2627343 | Samsung | CL05B104KO5NNNC | TME | CL05B104KO5NN NC

C4, C6 | 0402 SMD Capacitor | DNP | | | 2
C5 | 0402 SMD Capacitor | 100p | 10% | 25V | 1 | Kyocera AVX | 04025A101JAT2A | TME | 04025A101JAT2A | Multicomp | MC0402B101K250CT | Farnell | 1758898
C9, C10 | 0402 SMD Capacitor | 10p | 5% | 50V | 2 | Vishay | VJ0402A100JXACW1BC | Farnell | 2896329 | Vishay Vitramon | VJ0402A100FXACW1B C | TME | VJ0402A100FXAC W1BC

D1 | LED; SMD; 3528,PLCC4; RGB; 3,5x2,8x1,9mm; 115°; 20mA; Common anode | | | | 1 | Broadcom Avago | ASMB-MTB1-0A3A2 | Farnell | 2401106 | Broadcom | ASMB-MTB1-0A3A2 | TME | ASMB-MTB1-0A3A2

F1 | PTC Fuse 500mA | | | | 1 | Excel Cell | SR075-06 | TME | SR075-06

FB1, FB2 | Ferrite Bead | 120@100MHz | 25% | | 2 | Murata | BLM15PD121SN1D | Farnell | 2443229 | Murata | BLM15PD121SN1D | TME | BLM15PD121SN1D
J1, J2, J3 | 1x2, 2.54mm Black header jumper | | | | 3 | Multicomp | MC-2228CG | Farnell | 2834673 | Ninigi | JUMPER-B | TME | JUMPER-B

P1, P7, P8 | Pin header, 1x3, 2.54mm | | | | 3 | Ningbo Connfly Electric | DS1021-1*3SF1-1 | TME | ZL201-03G

P2 | Hirose UFL connector | | | | 1 | Hirose | U.FL-R-SMT-1(10) | Farnell | 1688077 | | | RS-Componen ts | 557-981

P3, P5 | Header, 16-Pin | | | | 2 | Harwin | M20-7821646 | Mouser | 855-M20-7821646 | Harwin | M20-7821646 | Mouser | 855-M20-7821646

P4 | Memory Card Connectors Micro SD 8 Pin PCB Gold | | | | 1 | Amphenol Commercial | 114-00841-68 | Farnell | 2666772 | Amphenol ICC | 1140084168 | Mouser | 523-114-00841-68

P6 | Gniazdo; USB B mini; SMT; poziome; V: USB 2.0; złocony | | | | 1 | Adam Tech | MUSB-B5-S-RA-TSMT-CS1 | TME | MUSB-B5-S-RA-SMT

R1, R5, R7, R12, R16, R17 | 0402 Film SMD Resistor | 1k | 1% | | 6 | TE Connectivity Neohm | CRG0402J1K0 | Farnell | 1174154 | Vishay | CRCW04021K00FKTD BC | TME | CRCW04021K00FK TDBC

R2, R3, R4, R6 | 0402 Film SMD Resistor | 150 | 1% | | 4 | TE Connectivity | CRGCQ0402F150R | Farnell | 2861390 | Yageo | RC0402FR-07150R | TME | RC0402FR-07150R

R8 | 0402 Film SMD Resistor | 0 | 1% | | 1 | Panasonic | ERJ-2GE0R00X | Farnell | ERJ2GE0R00X
R11, R13, R14 | 0402 Film SMD Resistor | 22k | 1% | | 3 | TE Connectivity | CRGCQ0402F22K | Farnell | 2861416 | Vishay | CRCW040222K0FKTD BC | TME | CRCW040222K0FK TDBC

R15 | 0402 Film SMD Resistor | 47k | 1% | | 1 | TE Connectivity | CRGCQ0402F47K | Farnell | 2861420 | Royal Electronic Factory | 0402WGF4702TCE | TME | SMD0402-47K-1%

S1, S2, S3 | TACT; SPST-NO; 2 position; 0,05A/12VDC; SMT | | | | 3 | Schurter | 1301.9319 | Farnell | 1217771 | Schurter | 1301.9319 | TME | 1301.9319
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

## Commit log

2018-10-20 Initial schematic design
    Added USB section
    W01 WiPy
    Added jumper selection for UART and 5V
    Added micro SD card holder
    Added 3.3V LDO
    Added low frequency oscillator
    [USB.SchDoc, WiPy_Eval.PcbDoc, WiPy_Eval.PrjPCB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]
2018-10-21 Finished Layout
    Added humidity/ temperature sensor
    Added current limiting resistors
    Changed antenna muxing
    Finished PCB Layout
    Generated Output files
    [Bill of Materials-WiPy_Eval.xls, USB.SchDoc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]
2019-02-17 Routing done
    [Bill of Materials-WiPy_Eval.xls, Bill of Materials-WiPy_uEval.xls, Display.SchDoc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]
2019-05-16 Prototype done -Fixed SIM socket footprint -Widened main fuse pads -placed safety diode after main fuse -added note with suggested power supply
    [Bill of Materials-WiPy_Eval.xls, Bill of Materials-WiPy_uEval.xls, Display.SchDoc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]
